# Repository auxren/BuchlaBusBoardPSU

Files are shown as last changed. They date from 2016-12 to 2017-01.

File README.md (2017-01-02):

# BuchlaBusBoardPSU
Powered bus board for Buchla synths. Takes in 15+VAC and outputs +/-15V, 12v, 5v with the edge connectors

On V1, the input and ground pins are swapped on the +5V and +12V regulator!!!! Be careful
V1 Build Instructions: https://docs.google.com/document/d/1-DcCvpJwsg8GtUNmFtXBNVGs2bGKTp7EB2MjyQB2pcI/edit?usp=sharing

V2 Build Instructions: https://docs.google.com/document/d/1IJPSkp8Wrz1e5LvetFv-_2ZjM5nTvgyAxMTtsMZAZh8/edit?usp=sharing

Mouser Cart: http://www.mouser.com/ProjectManager/ProjectDetail.aspx?AccessID=625fe8b728

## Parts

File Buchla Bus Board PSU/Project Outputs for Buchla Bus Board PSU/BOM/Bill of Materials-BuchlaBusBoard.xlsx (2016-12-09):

Description | Designator | Distributor | Distributor_Pn | Mfr | Mfr_Pn | Quantity
100uF Electrolytic | C1, C5 | Mouser | 598-107TTA050M | Illinois | 107TTA050M | 2
105TTA050M | C2, C3, C6, C7, C10, C11, C12 | Mouser | 598-105TTA050M | Illinois | 105TTA050M | 7
.1uF Cap | C4, C8, C13, C14 | Mouser | 594-2222-371-78104 | Vishay | BFC237178104 | 4
10uF Electrolytic | C9 | Mouser | 598-106TTA050M | Illinois | 106TTA050M | 1
1.0 A Rectifier, 15 pF, 50 V, -65 to 150 degC, 2-Pin DO-41 Plastic, RoHS, Tape and Reel | D1, D2 | Mouser | 621-1N4001 | Diodes Inc | 1N4001-T | 2
15V Positive Regulator | L1 | Mouser | 511-L7815ABV | ST | L7815ABV | 1
3-Terminal Negative Regulator, 3-pin TO-220 | LM1 | Mouser | 512-LM7915CT | Fairchild | LM7915CT | 1
3-Terminal Negative Regulator, 3-pin TO-220 | LM2 | Mouser | 512-LM7812CT | Fairchild | LM7812CT | 1
3-Terminal Negative Regulator, 3-pin TO-220 | LM3 | Mouser | 512-LM7805CT | Fairchild | LM7805CT | 1

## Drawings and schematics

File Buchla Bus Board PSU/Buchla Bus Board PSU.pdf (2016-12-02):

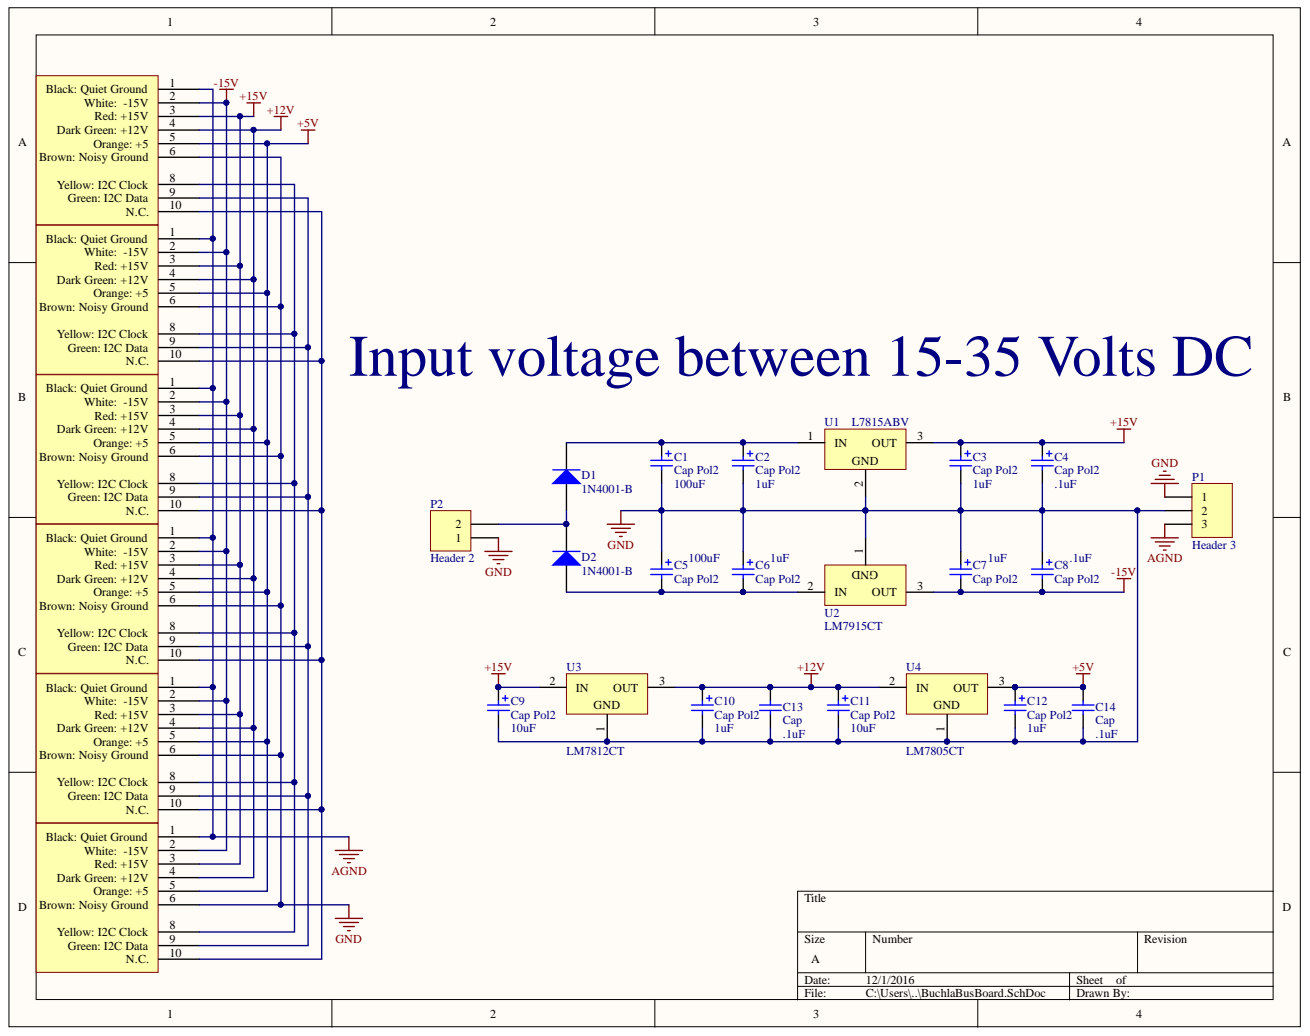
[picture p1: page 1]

Input voltage between 15-35 Volts DC

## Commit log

2016-12-02 First Commit of Buchla Bus Board PSU
    Need to change the board shape a bit for the regulators to sit flat.
    [Buchla Bus Board PSU.PrjPcb, Buchla6PosDist.PcbDoc, BuchlaBusBoard.SchDoc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]
2016-12-02 Files Submitted to fab
    Fixed board shape for bent regulators. Cleaned up silkscreen.
    [Buchla Bus Board PSU.PrjPcb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]
2016-12-09 Created BOM and Cleaned up PN
    The 12V and 5V regulators have the Ground and Input pins swapped!
    [Bill of Materials-BuchlaBusBoard.xlsx]
2016-12-09 Powered Bus Board V2
    Fixed Pinout for +5V and +12V regulators
    [Bill of Materials-BuchlaBusBoard.xlsx, Buchla Bus Board PSU.PrjPcb, Buchla6PosDist.PcbDoc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]
2016-12-09 Added V2 Fab Files
    [Buchla6PosDist.GBL, Buchla6PosDist.GBO, Buchla6PosDist.GBP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]
2016-12-16 V2 Release with udated hole sizes for caps and new
    [Buchla6PosDist.GBL, Buchla6PosDist.GBO, Buchla6PosDist.GBP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]
